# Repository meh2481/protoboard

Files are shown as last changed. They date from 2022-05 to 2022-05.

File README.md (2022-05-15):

# Protoboard
Prototyping board for pi pico development, with some useful features:
- SD card reader
- Test LEDs
- DAC/Speaker
- Pushbuttons
- OLED Display
- 12V->5V buck converter
- USB-C/MicroUSB power in
- Pico pinout protoboard

# Materials
Parts used:
- 1x [I2C OLED Display](https://smile.amazon.com/dp/B09C5K91H7)
- 1x [Pi Pico Breadboard](https://www.adafruit.com/product/5422)
- 1x [3A Fuse](https://smile.amazon.com/dp/B07L8K28N7)
- 2x [Fuse Holder](https://smile.amazon.com/dp/B07SKG4M78)
- 1x [12V Power Supply](https://smile.amazon.com/dp/B01GEA8PQA), optional
- 3x [400-Pin Protoboard](https://smile.amazon.com/dp/B07LFD4LT6)
- 1x [USB-C Connector](https://www.mouser.com/ProductDetail/640-USB4085-GF-A)
- 1x [MicroUSB Connector](https://www.mouser.com/ProductDetail/640-USB3076-30-A)
- 1x [5V Voltage Regulator](https://www.mouser.com/ProductDetail/863-LM2576TV-5G)
- 2x [Shottky Diode](https://www.mouser.com/ProductDetail/583-1N5822-T)
- 1x [100uH Inductor](https://www.mouser.com/ProductDetail/530-HCTI-100-7.0)
- 1x [DC Power Jack](https://www.mouser.com/ProductDetail/490-PJ-102AH)
- 1x [MicroSD connector](https://www.digikey.com/en/products/detail/molex/1040310811/2370379)
- 1x [Speaker](https://www.digikey.com/en/products/detail/db-unlimited/SM231508-1/9990601)
- 5x [2x2 2.54mm Female Pin Header](https://www.digikey.com/en/products/detail/sullins-connector-solutions/PPTC022LFBN-RC/810209)
- 8x M2x8 screws
- 4x M2.5x4-ish screws
- 1x 1x4 2.54mm Female Pin Header
- 1x 1x8 2.54mm Female Pin Header
- 4x 6mm Push Buttons
- Various resistors/capacitors/LEDs/switches

# Improvements
This project is complete, but if you make it you'll probably want to make some changes.
- Power LED resistor should go to GND, not GND_SWITCHED. That way LED is off when switch is off.
- Protoboards seem off-center? Probably not measured correctly.
- Smaller inductor; current one is probably overkill.
- Buck converter on right side of board, not left (or pico protoboard on right side) for easier wiring when prototyping.
- Amp like [this one](https://www.adafruit.com/product/2130) for speaker works really well if you can fit it on the board.
- 5V->3V3 stepdown might be a good idea if you don't want to be tied to the pico's power supply.
- Better PCB labels/warnings against using 3V3 on SD card/etc.

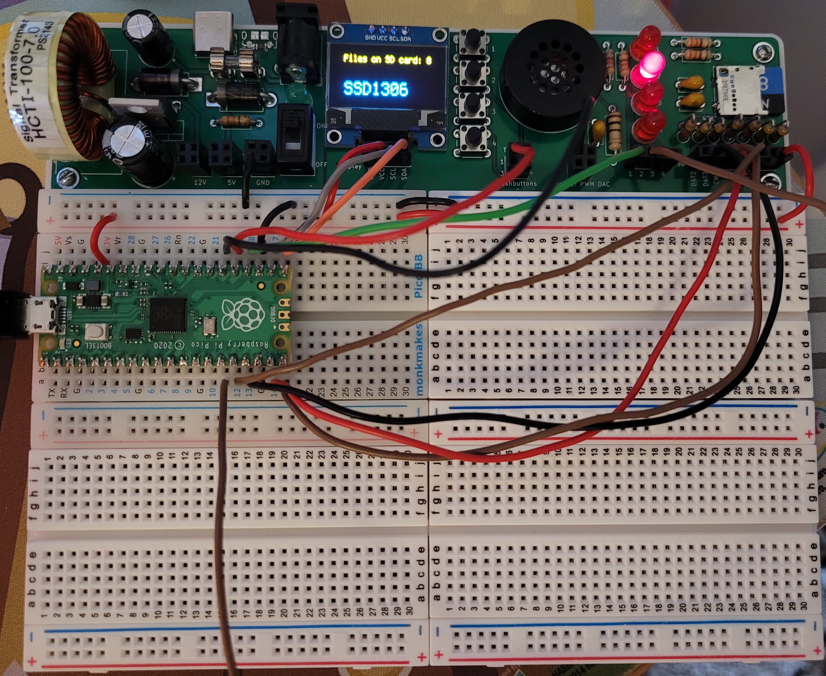
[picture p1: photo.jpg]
Picture of protoboard


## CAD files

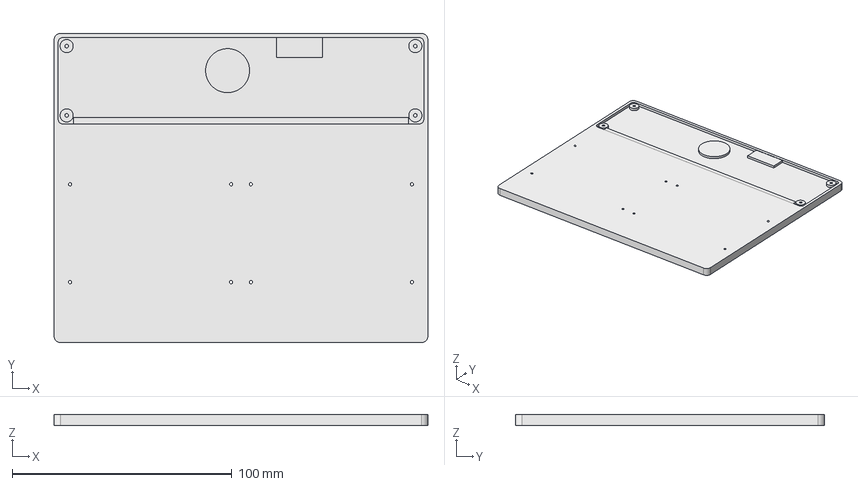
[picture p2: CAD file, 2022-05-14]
freecad/protoboard.fcstd
170.0 x 140.5 x 5.00 mm

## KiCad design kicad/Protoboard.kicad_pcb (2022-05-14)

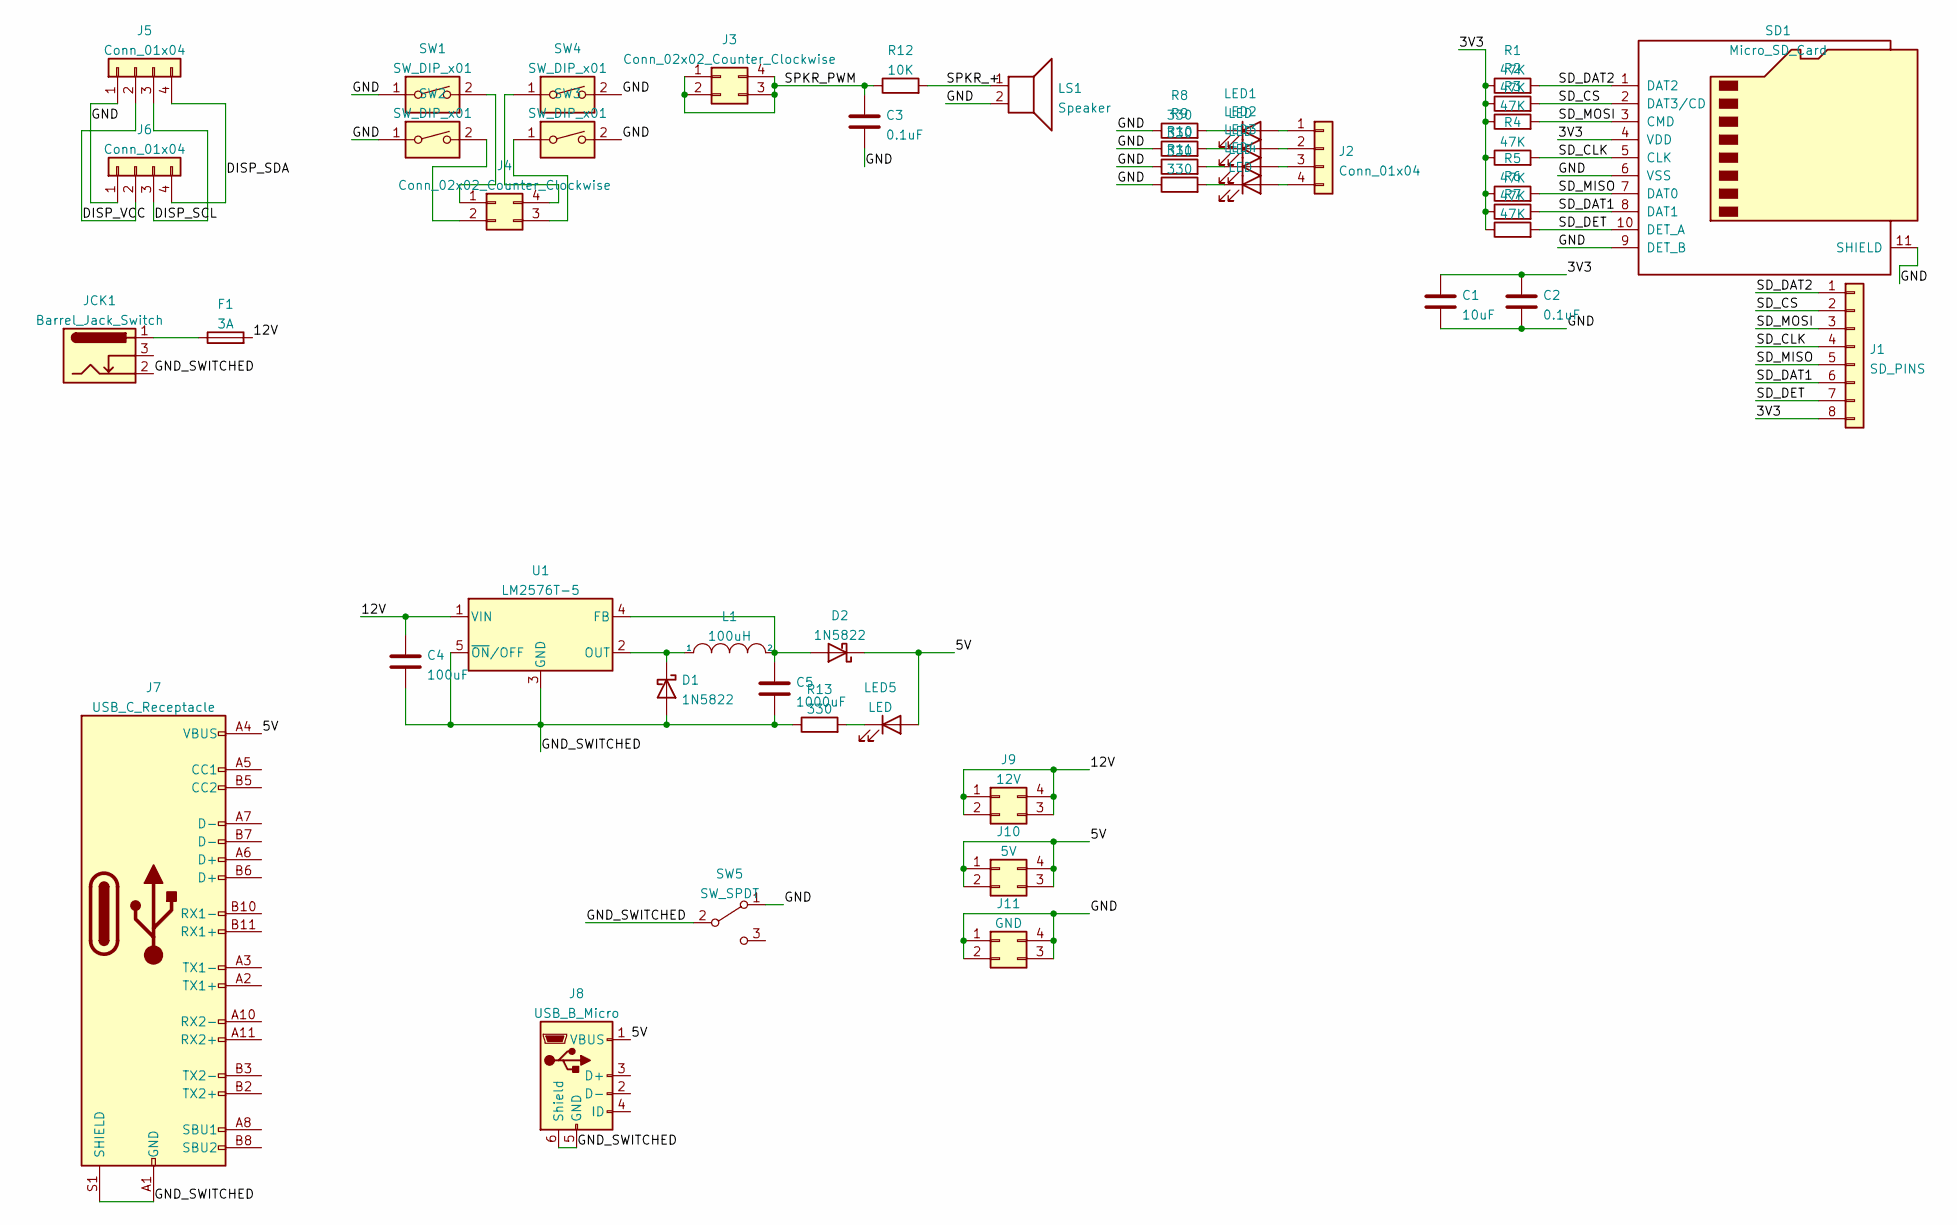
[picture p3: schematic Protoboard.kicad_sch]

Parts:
C1: 10uF; C_Disc_D5.1mm_W3.2mm_P5.00mm
C2, C3: 0.1uF; C_Disc_D5.1mm_W3.2mm_P5.00mm
C4: 100uF; CP_Radial_D8.0mm_P3.50mm
C5: 1000uF; CP_Radial_D10.0mm_P5.00mm
D1, D2: 1N5822; D_DO-201AD_P12.70mm_Horizontal
F1: 3A; FuseHolder_3.5x9.75mm
J1: SD_PINS; PinSocket_1x08_P2.54mm_Vertical
J2, J6: Conn_01x04; PinSocket_1x04_P2.54mm_Vertical
J3, J4: Conn_02x02_Counter_Clockwise; PinSocket_2x02_P2.54mm_Vertical
J5: Conn_01x04; PinHeader_1x04_P2.54mm_Vertical
J7: USB_C_Receptacle; USB_C_Receptacle_GCT_USB4085
J8: USB_B_Micro; USB_Micro-B_GCT_USB3076-30-A
J9: 12V; PinSocket_2x02_P2.54mm_Vertical
J10: 5V; PinSocket_2x02_P2.54mm_Vertical
J11: GND; PinSocket_2x02_P2.54mm_Vertical
JCK1: Barrel_Jack_Switch; BarrelJack_CUI_PJ-102AH_Horizontal
L1: 100uH; L_Toroid_Vertical_L28.6mm_W14.3mm_P11.43mm_Bourns_5700
LED1, LED2, LED3, LED4, LED5: LED; LED_D5.0mm
LS1: Speaker; Buzzer_D14mm_H7mm_P10mm
R1, R2, R3, R4, R5, R6, R7: 47K; R_Axial_DIN0207_L6.3mm_D2.5mm_P2.54mm_Vertical
R8, R9, R10, R11, R13: 330; R_Axial_DIN0207_L6.3mm_D2.5mm_P10.16mm_Horizontal
R12: 10K; R_Axial_DIN0309_L9.0mm_D3.2mm_P12.70mm_Horizontal
SD1: Micro_SD_Card; microSD_HC_Molex_104031-0811
SW1, SW2, SW3, SW4: SW_DIP_x01; SW_PUSH_6mm_H7.3mm
SW5: SW_SPDT; PinHeader_1x03_P2.54mm_Vertical
U1: LM2576T-5; TO-220-5_P3.4x3.7mm_StaggerOdd_Lead3.8mm_Vertical

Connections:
/3V3: C1.1, C2.1, J1.8, R1.1, R2.1, R3.1, R4.1, R5.1, R6.1, R7.1, SD1.4 (VDD)
/5V: D2.1 (K), J7.A4 (VBUS), J7.A9 (VBUS), J7.B4 (VBUS), J7.B9 (VBUS), J8.1 (VBUS), J10.1, J10.2, J10.3, J10.4, LED5.2 (A)
/12V: C4.1, F1.2, J9.1, J9.2, J9.3, J9.4, U1.1 (VIN)
/DISP_SCL: J5.3, J6.3
/DISP_SDA: J5.4, J6.4
/DISP_VCC: J5.2, J6.2
/GND: C1.2, C2.2, C3.2, J5.1, J6.1, J11.1, J11.2, J11.3, J11.4, LS1.2, R8.1, R9.1, R10.1, R11.1, SD1.6 (VSS), SD1.9 (DET_B), SD1.11 (SHIELD), SW1.1, SW2.1, SW3.2, SW4.2, SW5.1 (A)
/GND_SWITCHED: C4.2, C5.2, D1.2 (A), J7.A1 (GND), J7.A12 (GND), J7.B1 (GND), J7.B12 (GND), J7.S1 (SHIELD), J8.5 (GND), J8.6 (Shield), JCK1.2, R13.1, SW5.2 (B), U1.3 (GND), U1.5 (~ON/OFF)
/SD_CLK: J1.4, R4.2, SD1.5 (CLK)
/SD_CS: J1.2, R2.2, SD1.2 (DAT3/CD)
/SD_DAT1: J1.6, R6.2, SD1.8 (DAT1)
/SD_DAT2: J1.1, R1.2, SD1.1 (DAT2)
/SD_DET: J1.7, R7.2, SD1.10 (DET_A)
/SD_MISO: J1.5, R5.2, SD1.7 (DAT0)
/SD_MOSI: J1.3, R3.2, SD1.3 (CMD)
/SPKR_+: LS1.1, R12.2
/SPKR_PWM: C3.1, J3.1, J3.2, J3.3, J3.4, R12.1
unnamed: D1.1 (K), L1.1, U1.2 (OUT)
unnamed: F1.1, JCK1.1
unnamed: J2.1, LED1.2 (A)
unnamed: J2.2, LED2.2 (A)
unnamed: J2.3, LED3.2 (A)
unnamed: J2.4, LED4.2 (A)
unnamed: J4.1, SW1.2
unnamed: J4.2, SW2.2
unnamed: J4.3, SW3.1
unnamed: J4.4, SW4.1
unnamed: C5.1, D2.2 (A), L1.2, U1.4 (FB)
unnamed: LED1.1 (K), R8.2
unnamed: LED2.1 (K), R9.2
unnamed: LED3.1 (K), R10.2
unnamed: LED4.1 (K), R11.2
unnamed: LED5.1 (K), R13.2

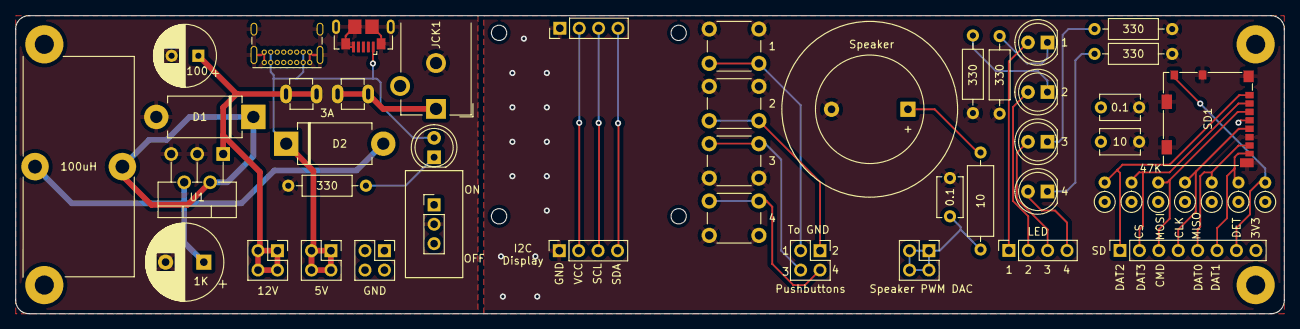
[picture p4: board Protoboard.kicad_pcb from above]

Board: 2 copper layers, 166.0 x 39.0 mm, 47 parts (0 on the bottom side), 33 nets.

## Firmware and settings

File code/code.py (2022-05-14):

# Hardware: Adafruit Qt Py 2040
import adafruit_displayio_ssd1306
import displayio
from adafruit_display_text import label
import terminalio
import board
import busio
import adafruit_sdcard
import os
import storage
import audiopwmio
from audiomp3 import MP3Decoder
from digitalio import DigitalInOut, Direction, Pull
from adafruit_debouncer import Debouncer

displayio.release_displays()

# Init display
WIDTH = 128
HEIGHT = 64
BORDER = 2
i2c = busio.I2C(board.GP17, board.GP16)
display_bus = displayio.I2CDisplay(i2c, device_address=0x3c)
display = adafruit_displayio_ssd1306.SSD1306(display_bus, width=WIDTH, height=HEIGHT)

# Make the display context
splash = displayio.Group()
display.show(splash)

# Draw black background
color_bitmap = displayio.Bitmap(WIDTH, HEIGHT, 1)
color_palette = displayio.Palette(1)
color_palette[0] = 0x0
bg_sprite = displayio.TileGrid(color_bitmap, pixel_shader=color_palette, x=0, y=0)
splash.append(bg_sprite)

# Label text
text1 = "Files on SD card: X"
text_area = label.Label(terminalio.FONT, text=text1, color=0xFFFFFF, x=8, y=8)
splash.append(text_area)
text2 = "SSD1306"
text_area2 = label.Label(
    terminalio.FONT, text=text2, scale=2, color=0xFFFFFF, x=9, y=44
)
splash.append(text_area2)

# Init Sd card
spi = busio.SPI(board.GP14, board.GP15, board.GP12)
cs = DigitalInOut(board.GP13)
sdcard = adafruit_sdcard.SDCard(spi, cs)
vfs = storage.VfsFat(sdcard)
storage.mount(vfs, "/sd")

# List files on SD card
print("Files on SD card:")
numfiles = 0
for filename in os.listdir("/sd"):
    numfiles += 1
    print(filename)

text_area.text = f'Files on SD card: {numfiles}'

# Init LED out
led = DigitalInOut(board.GP18)
led.direction = Direction.OUTPUT
led.value = False
led2 = DigitalInOut(board.GP11)
led2.direction = Direction.OUTPUT
led2.value = False

# Init button in
button = DigitalInOut(board.GP19)
button.direction = Direction.INPUT
button.pull = Pull.UP

# Init audio file
mp3file = open("/PINBALL-sm.mp3", "rb")
decoder = MP3Decoder(mp3file)
audio = audiopwmio.PWMAudioOut(board.GP20)

debouncer = Debouncer(button)

# Main loop
while True:
    audio.play(decoder)
    while audio.playing:
        debouncer.update()
        if debouncer.fell:
            # Button is pressed
            led.value = True
            led2.value = not led2.value
        elif debouncer.rose:
            # Button is not pressed
            led.value = False
